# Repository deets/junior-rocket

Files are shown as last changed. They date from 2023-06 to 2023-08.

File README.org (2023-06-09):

* Junior Rocket Firmware

This repository contains the Arduino based firmware for the FAR Junior
two stage rocket.

** RP2040

The state machine is written in C++17. To allow for this to work with
Arduino, the =platform.txt= needs to change so that it enables C++17.

On my system, this is the file

 =~/Library/Arduino15/packages/arduino/hardware/mbed_rp2040/4.0.2/=

The following line must be present:

#+begin_src python
compiler.cpp.extra_flags=-std=gnu++17
#+end_src

Compile with

#+begin_src bash
arduino-cli compile --fqbn arduino:mbed_rp2040:pico
#+end_src

** Arduino Maple

Compile with

#+begin_src bash
arduino-cli compile --fqbn STMicroelectronics:stm32:GenF1 --board-options "pnum=MAPLEMINI_F103CB,opt=oslto"
#+end_src

*** Linker optimization in platform.txt

Lives in

#+begin_src bash
~/Library/Arduino15/packages/STMicroelectronics/hardware/stm32/2.5.0/
#+end_src

for me. Make the following settings look like this:

#+begin_src python
compiler.ldflags=-Wl,--no-warn-rwx-segments,--gc-sections
compiler.c.extra_flags=-ffunction-sections -fdata-sections
compiler.cpp.extra_flags=-ffunction-sections -fdata-sections
#+end_src

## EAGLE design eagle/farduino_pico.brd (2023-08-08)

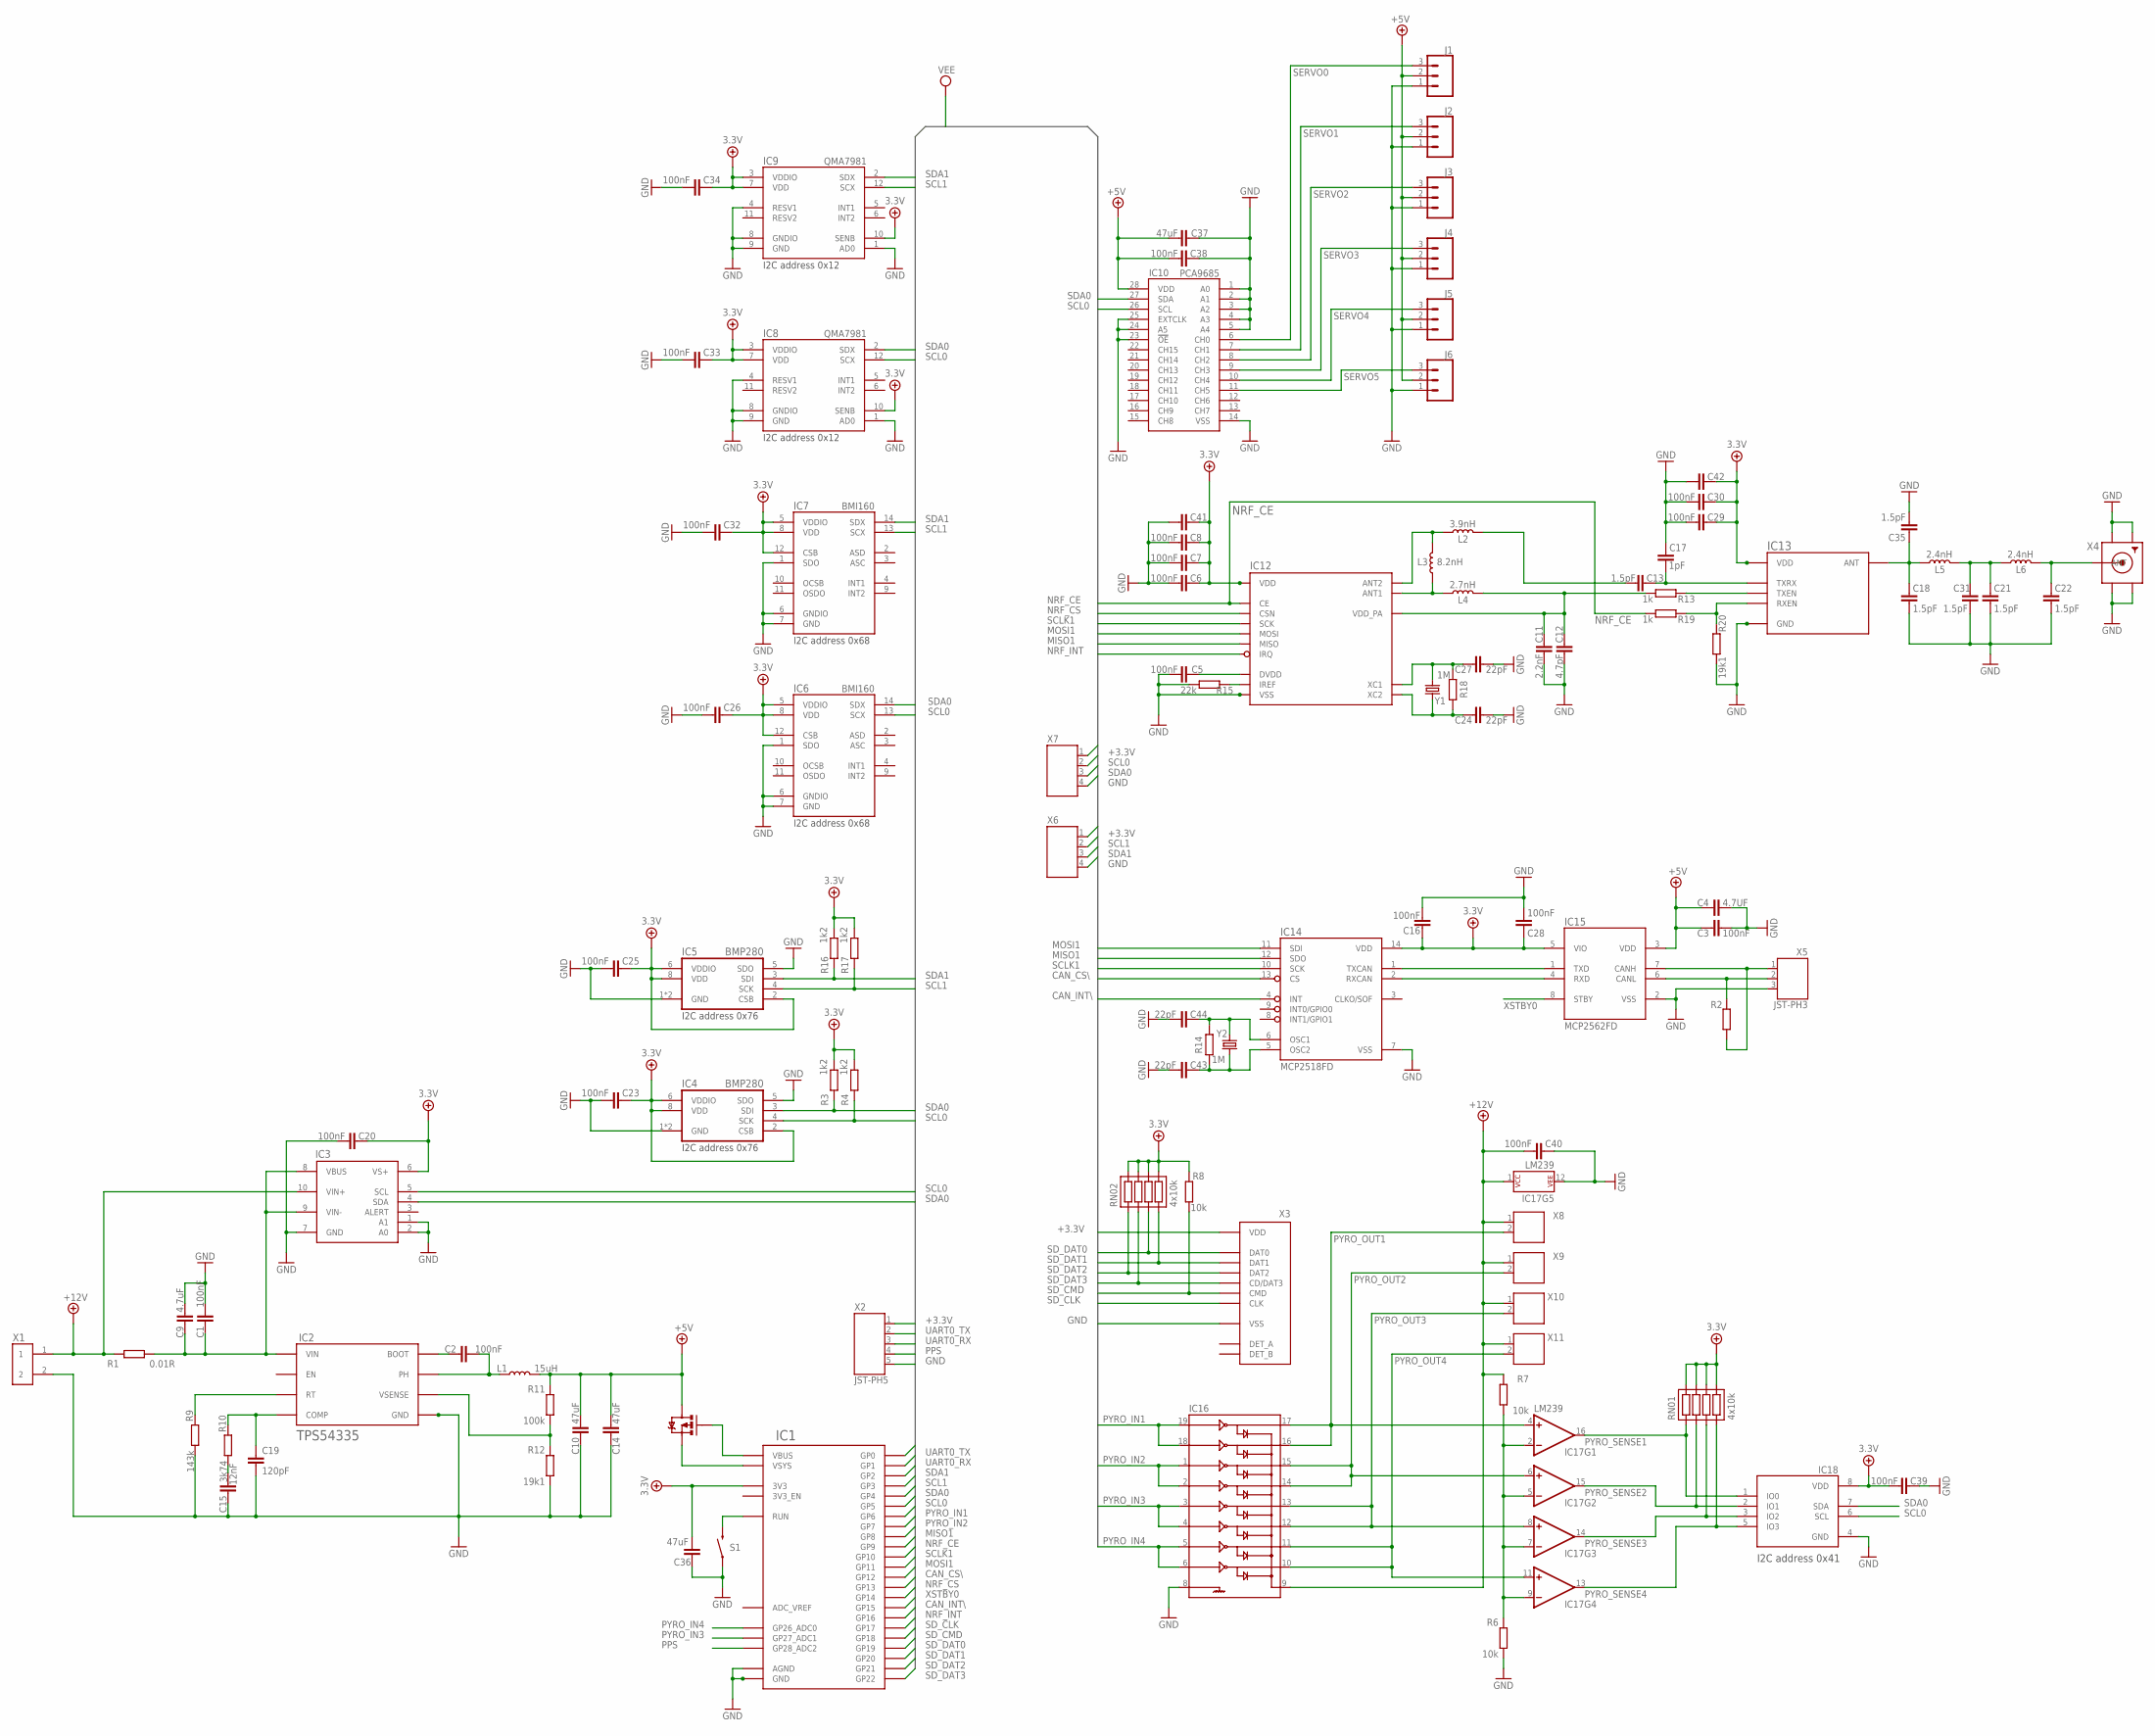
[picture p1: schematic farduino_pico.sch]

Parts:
C1, C2, C3, C5, C6, C7, C8, C16, C20, C23, C25, C26, C28, C29, C30, C32, C33, C34, C38, C39, C40: 100nF; 0402
C4, C41, C42: 4.7UF; 0402
C9: 4.7uF; 1206
C10, C14, C36, C37: 47uF; 1206
C11: 2.2nF; C0402
C12: 4.7pF; C0402
C13, C18, C21, C22, C31, C35: 1.5pF; C0402
C15: 12nF; C0402
C17: 1pF; C0402
C19: 120pF; C0402
C24, C27, C43, C44: 22pF; C0402
IC1: RPI_PICO-SMD; RPI_PICO
IC2: TPS54335ADRCR; VSON-10
IC3: INA226; VSSOP-10
IC4, IC5: BMP280
IC6, IC7: BMI160
IC8, IC9: QMA7981; LGA-12-2X2
IC10: PCA9685; TSSOP-28_4MM
IC12: NRF24L01SMD; QFN20-4X4MM
IC13: RFX2401C; QFN-16-3X3MM
IC14: MCP2518FD; SO14
IC15: MCP2562FD; SO08
IC16: ULN2803QFN; QFN-20-4X4
IC17: LM239; QFN16
IC18: PCA9536; HVSON8
J1, J2, J3, J4, J5, J6: CONN_03; 1X03
L1: 15uH; YSPIA0850
L2: 3.9nH; 0402
L3: 8.2nH; 0402
L4: 2.7nH; 0402
L5, L6: 2.4nH; 0402
Q1: DMG2305UX; SOT23-3@1
R1: 0.01R; R1206
R2: 120; R0402
R3, R4, R16, R17: 1k2; R0402
R6, R7, R8: 10k; R0402
R9: 143k; R0402
R10: 3k74; R0402
R11: 100k; R0402
R12, R20: 19k1; R0402
R13, R19: 1k; R0402
R14, R18: 1M; R0402
R15: 22k; R0402
RN01, RN02: 4x10k; 4D02
S1: MOMENTARY-SWITCH-SPST; TACTILE_SWITCH_SMD_4.2X3.2MM
X1: XT_CONN; XT30_PCB
X2: JST-PH5
X3: 5033981892
X4: SMACONNECTOR; SMA90_DIP
X5: JST-PH3
X6, X7: JST-PH4
X8, X9, X10, X11: JST-PH2
Y1, Y2: CRYSTAL-16MHZ; SMD3225

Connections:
+3.3V: C6.1, C7.1, C8.1, C16.1, C20.2, C23.1, C25.1, C26.1, C28.1, C29.1, C30.1, C32.1, C33.1, C34.1, C36.2, C39.2, C41.2, C42.2, IC1.3V3, IC3.6 (VS+), IC4.2 (CSB), IC4.6 (VDDIO), IC4.8 (VDD), IC5.2 (CSB), IC5.6 (VDDIO), IC5.8 (VDD), IC6.5 (VDDIO), IC6.8 (VDD), IC6.12 (CSB), IC7.5 (VDDIO), IC7.8 (VDD), IC7.12 (CSB), IC8.3 (VDDIO), IC8.7 (VDD), IC8.10 (SENB), IC9.3 (VDDIO), IC9.7 (VDD), IC9.10 (SENB), IC12.7 (VDD), IC12.15 (VDD), IC12.18 (VDD), IC13.14 (VDD), IC13.16 (VDD), IC14.14 (VDD), IC15.5 (VIO), IC18.8 (VDD), R3.2, R4.2, R8.2, R16.2, R17.2, RN01.5, RN01.6, RN01.7, RN01.8, RN02.5, RN02.6, RN02.7, RN02.8, X2.1, X3.4 (VDD), X6.1, X7.1
+5V: C3.1, C4.1, C10.2, C14.2, C37.2, C38.2, IC10.28 (VDD), IC15.3 (VDD), J1.2, J2.2, J3.2, J4.2, J5.2, J6.2, L1.2, Q1.3 (D), R11.2
+12V: C40.2, IC3.10 (VIN+), IC16.9 (COM), IC17.1 (P$V+), R1.2, R7.2, X1.1, X8.1, X9.1, X10.1, X11.1
ANT1: IC12.12 (ANT1), L3.1, L4.1
ANT2: IC12.13 (ANT2), L2.1, L3.2
CAN1_H: IC15.7 (CANH), R2.1, X5.1
CAN1_L: IC15.6 (CANL), R2.2, X5.2
CAN_CS\: IC1.GP12, IC14.13 (CS)
CAN_INT\: IC1.GP15, IC14.4 (INT)
DCDC_BOOT: C2.2, IC2.9 (BOOT)
DCDC_COMP: C19.1, IC2.7 (COMP), R10.1
DCDC_PH: C2.1, IC2.2 (PH), L1.1
DCDC_RT: IC2.10 (RT), R9.1
DVDD: C5.1, IC12.19 (DVDD)
FILTER1: C21.1, C31.1, L5.2, L6.1
GND: C1.1, C3.2, C4.2, C5.2, C6.2, C7.2, C8.2, C9.2, C10.1, C11.2, C12.2, C14.1, C15.2, C16.2, C17.1, C18.2, C19.2, C20.1, C21.2, C22.2, C23.2, C24.2, C25.2, C26.2, C27.2, C28.2, C29.2, C30.2, C31.2, C32.2, C33.2, C34.2, C35.2, C36.1, C37.1, C38.1, C39.1, C40.1, C41.1, C42.1, C43.2, C44.2, IC1.AGND, IC1.GND@1 (GND), IC1.GND@2 (GND), IC1.GND@3 (GND), IC1.GND@4 (GND), IC1.GND@5 (GND), IC1.GND@6 (GND), IC1.GND@7 (GND), IC1.GND@8 (GND), IC2.3 (GND), IC2.4 (GND), IC2.5 (GND), IC2.11 (GND), IC3.1 (A1), IC3.2 (A0), IC3.7 (GND), IC4.1 (GND), IC4.5 (SDO), IC4.7 (GND), IC5.1 (GND), IC5.5 (SDO), IC5.7 (GND), IC6.1 (SDO), IC6.6 (GNDIO), IC6.7 (GND), IC7.1 (SDO), IC7.6 (GNDIO), IC7.7 (GND), IC8.1 (AD0), IC8.4 (RESV1), IC8.8 (GNDIO), IC8.9 (GND), IC9.1 (AD0), IC9.4 (RESV1), IC9.8 (GNDIO), IC9.9 (GND), IC10.1 (A0), IC10.2 (A1), IC10.3 (A2), IC10.4 (A3), IC10.5 (A4), IC10.14 (VSS), IC10.23 (!OE), IC10.24 (A5), IC10.25 (EXTCLK), IC12.0 (VSS), IC12.8 (VSS), IC12.14 (VSS), IC12.17 (VSS), IC12.20 (VSS), IC13.1 (GND), IC13.2 (GND), IC13.3 (GND), IC13.7 (GND), IC13.8 (GND), IC13.9 (GND), IC13.11 (GND), IC13.12 (GND), IC13.15 (GND), IC13.17 (GND), IC14.7 (VSS), IC15.2 (VSS), IC16.8 (GND), IC17.12 (P$V-), IC18.4 (GND), J1.1, J2.1, J3.1, J4.1, J5.1, J6.1, R6.1, R9.2, R12.1, R15.1, R20.1, S1.1, S1.2 (1), X1.2, X2.5, X3.6 (VSS), X4.GND1, X4.GND2, X4.GND3, X4.GND4, X5.3, X6.4, X7.4
IREF: IC12.16 (IREF), R15.2
MISO1: IC1.GP8, IC12.5 (MISO), IC14.12 (SDO)
MOSI1: IC1.GP11, IC12.4 (MOSI), IC14.11 (SDI)
unnamed: C15.1, R10.2
NRF_CE: IC1.GP9, IC12.1 (CE), R19.1
NRF_CS: IC1.GP13, IC12.2 (CSN)
NRF_INT: IC1.GP16, IC12.6 (IRQ)
NRF_SIGNAL: C13.2, L2.2
OSC1_40MHZ: C44.1, IC14.6 (OSC1), R14.2, Y2.3 (2)
OSC2_40MHZ: C43.1, IC14.5 (OSC2), R14.1, Y2.1
PA_ANT: C18.1, C35.1, IC13.10 (ANT), L5.1
PPS: IC1.GP28_A2 (GP28_ADC2), X2.4
PYRO_IN1: IC1.GP6, IC16.18 (IN2), IC16.19 (IN1)
PYRO_IN2: IC1.GP7, IC16.1 (IN3), IC16.2 (IN4)
PYRO_IN3: IC1.GP27_A1 (GP27_ADC1), IC16.3 (IN5), IC16.4 (IN6)
PYRO_IN4: IC1.GP26_A0 (GP26_ADC0), IC16.5 (IN7), IC16.6 (IN8)
PYRO_OUT1: IC16.16 (OUT2), IC16.17 (OUT1), IC17.4 (+IN), X8.2
PYRO_OUT2: IC16.14 (OUT4), IC16.15 (OUT3), IC17.6 (+IN), X9.2
PYRO_OUT3: IC16.12 (OUT6), IC16.13 (OUT5), IC17.8 (+IN), X10.2
PYRO_OUT4: IC16.10 (OUT8), IC16.11 (OUT7), IC17.11 (+IN), X11.2
PYRO_SENSE1: IC17.16 (OUT), IC18.1 (IO0), RN01.1
PYRO_SENSE2: IC17.15 (OUT), IC18.2 (IO1), RN01.2
PYRO_SENSE3: IC17.14 (OUT), IC18.3 (IO2), RN01.3
PYRO_SENSE4: IC17.13 (OUT), IC18.5 (IO3), RN01.4
RUN: IC1.RUN, S1.3 (2), S1.4 (2)
RXCAN1: IC14.2 (RXCAN), IC15.4 (RXD)
RXEN: IC13.6 (RXEN), R19.2, R20.2
SCL0: IC1.GP5, IC3.5 (SCL), IC4.4 (SCK), IC6.13 (SCX), IC8.12 (SCX), IC10.26 (SCL), IC18.6 (SCL), R4.1, X7.2
SCL1: IC1.GP3, IC5.4 (SCK), IC7.13 (SCX), IC9.12 (SCX), R17.1, X6.2
SCLK1: IC1.GP10, IC12.3 (SCK), IC14.10 (SCK)
SDA0: IC1.GP4, IC3.4 (SDA), IC4.3 (SDI), IC6.14 (SDX), IC8.2 (SDX), IC10.27 (SDA), IC18.7 (SDA), R3.1, X7.3
SDA1: IC1.GP2, IC5.3 (SDI), IC7.14 (SDX), IC9.2 (SDX), R16.1, X6.3
SD_CLK: IC1.GP17, X3.5 (CLK)
SD_CMD: IC1.GP18, R8.1, X3.3 (CMD)
SD_DAT0: IC1.GP19, RN02.3, X3.7 (DAT0)
SD_DAT1: IC1.GP20, RN02.4, X3.8 (DAT1)
SD_DAT2: IC1.GP21, RN02.1, X3.1 (DAT2)
SD_DAT3: IC1.GP22, RN02.2, X3.2 (CD/DAT3)
SERVO0: IC10.6 (CH0), J1.3
SERVO1: IC10.7 (CH1), J2.3
SERVO2: IC10.8 (CH2), J3.3
SERVO3: IC10.9 (CH3), J4.3
SERVO4: IC10.10 (CH4), J5.3
SERVO5: IC10.11 (CH5), J6.3
SMA_RF: C22.1, L6.2, X4.ANTENNA (ANT)
TXCAN1: IC14.1 (TXCAN), IC15.1 (TXD)
TXEN: IC13.5 (TXEN), R13.2
TXRX: C13.1, C17.2, IC13.4 (TXRX)
UART0_RX: IC1.GP1, X2.3
UART0_TX: IC1.GP0, X2.2
UREF: IC17.2 (-IN), IC17.5 (-IN), IC17.7 (-IN), IC17.9 (-IN), R6.2, R7.1
VBUS: IC1.VBUS, Q1.1 (G)
VDD_PA: C11.1, C12.1, IC12.11 (VDD_PA), L4.2, R13.1
VIN: C1.2, C9.1, IC2.1 (VIN), IC3.8 (VBUS), IC3.9 (VIN-), R1.1
VSENSE: IC2.6 (VSENSE), R11.1, R12.2
VSYS: IC1.VSYS, Q1.2 (S)
XC1_16MHZ: C27.1, IC12.10 (XC1), R18.1, Y1.1
XC2_16MHZ: C24.1, IC12.9 (XC2), R18.2, Y1.3 (2)
XSTBY0: IC1.GP14, IC15.8 (STBY)

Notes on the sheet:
I2C address 0x41
I2C address 0x76
I2C address 0x68
I2C address 0x12

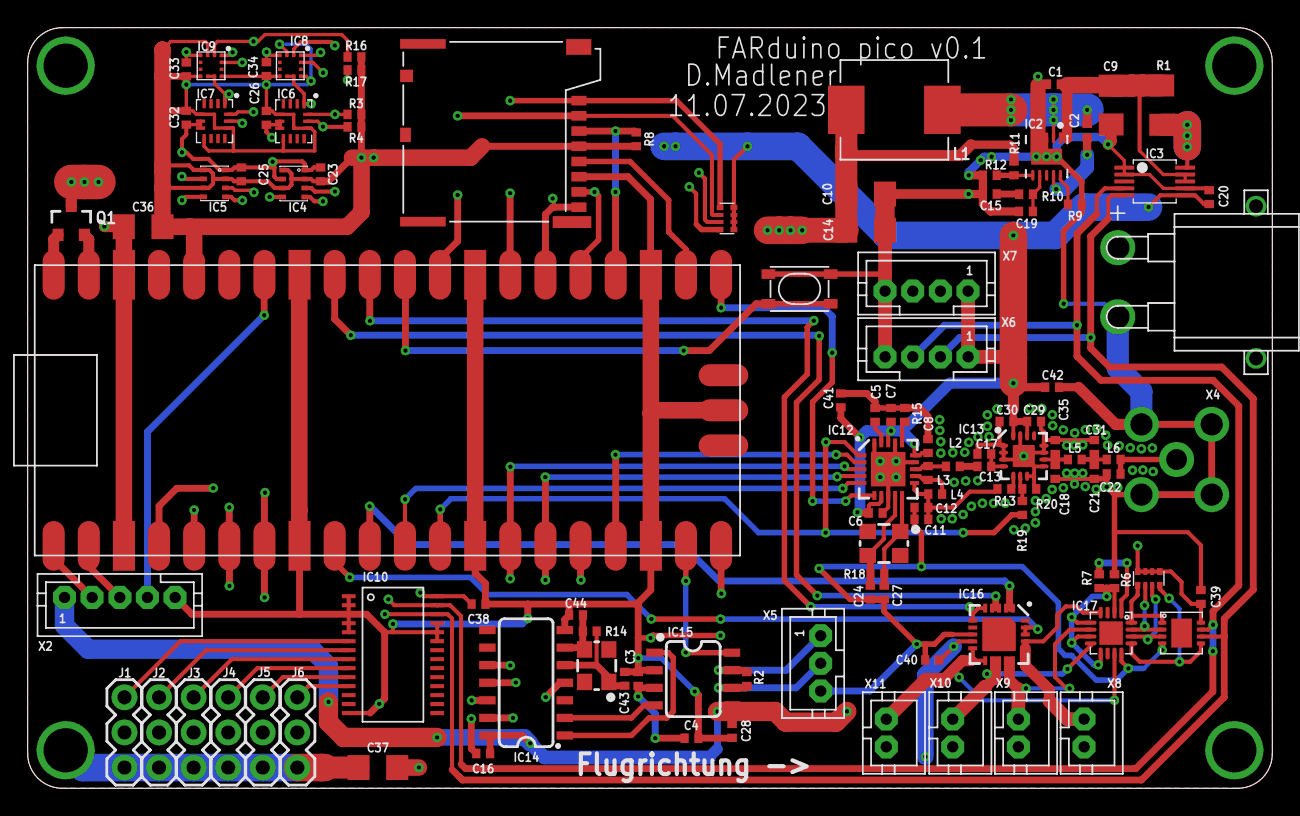
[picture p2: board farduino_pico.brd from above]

Board: 4 copper layers, 90.0 x 55.0 mm, 109 parts (0 on the bottom side), 75 nets.

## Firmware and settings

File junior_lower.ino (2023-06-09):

#include "farduino_constants.h"
// Must come after farduino_constants.h !
#include "rtttl_songs.h"
#include "farduino_types.h"
#include "farduino_utilities.h"
#include "ring_buffer.h"

#include "junior-rocket-state.hpp"
#include "state-reactions.hpp"

#include <I2Cdev.h>
#include <Wire.h>
#include <MPU9250.h>
#include <Adafruit_Sensor.h>
#include <Adafruit_BMP280.h>
#include <Adafruit_BNO055.h>
#include <utility/imumaths.h>

#ifdef USE_SD_CARD
#define USE_STANDARD_SPI_LIBRARY 2  // See SdFatConfig.h
#include <SPI.h>
#include <SdFat.h>
#endif

#include <RF24.h>

#include <chrono>

//#define farduino_maple_v1 1
#define farduino_maple_v2 1
//#define farduino_maple_v3 1



#define isdigit(n) (n >= '0' && n <= '9')

// class default I2C address is 0x68
// specific I2C addresses may be passed as a parameter here
// AD0 low  = 0x68 (default for InvenSense evaluation board)
// AD0 high = 0x69

char my_name[16];
char my_line[64];
char response[64];

unsigned int sample_count = 0;
unsigned int file_count = 0;

double temperature;
double pressure;
double altitude;

double raw_acc[3];
double raw_omega[3];
double raw_B[3];

double acc[3];
double omega[3];
double omega_0[3] = { 0.0, 0.0, 0.0 };
double B[3];

double norm_acc;
double norm_omega;

unsigned char GPS_checksum = 0;
byte unsigned GPS_pointer = 0;
bool receiving_GPS;
char GPS_sentence[128];

//the pressure sensor is necessary
Adafruit_BMP280 met;

MPU9250 imu_mpu9250;
bool mpu9250_present = false;

Adafruit_BNO055 imu_bno055 = Adafruit_BNO055(-1, 0x28);
bool bno055_present = false;

byte flight_address[6] = "LOWER";
byte ground_address[6] = "GRND1";

char request[32] = "abcdefghijklmnopqrstuvwxyz01234";

CircularBuffer ring(256);
RF24 radio_nrf24(NRF24_CE_PIN, NRF24_CS_PIN);

bool nrf24l01_present = false;


#ifdef USE_SD_CARD
//SD constants and variables
const uint8_t chipSelect = PB12;
SPIClass spi2;
SdFat sd(&spi2);

bool SD_present = false;
SdFile dataFile;
bool file_exists;
#endif

StateReactions state_reactions(radio_nrf24);
far::junior::JuniorRocketState state_machine(state_reactions);

void setup() {

  double altitude;
  unsigned long met_timestamp;
  double sigma_w;

  unsigned long mean_count;

  inertial_measurement_t imu_data;

  //set all pyro pins as outputs and inactive
  pinMode(PYRO0, OUTPUT);
  digitalWrite(PYRO0, LOW);
  pinMode(PYRO1, OUTPUT);
  digitalWrite(PYRO1, LOW);
  pinMode(PYRO2, OUTPUT);
  digitalWrite(PYRO2, LOW);
  pinMode(PYRO3, OUTPUT);
  digitalWrite(PYRO3, LOW);

  //join I2C bus
  Wire.begin();
  Wire.setClock(100000);

  //open USB com port
  #ifndef RASPBERRYPI_PICO
  Serial.begin(115200);
  #else
  Serial.begin(115200);
  #endif

  //serial port #1 set to 9600 8n1 for GPS data stream
  Serial1.begin(9600);

  delay(2000);
  Serial.println(F("FARduino Maple v0.2"));


  nrf24l01_present = radio_nrf24.begin();
  if (nrf24l01_present) {
    Serial.print(F("Initializing nrf24L01+..."));

    radio_nrf24.setPayloadSize(32);
    radio_nrf24.setAutoAck(true);
    radio_nrf24.setPALevel(RF24_PA_LOW);
    radio_nrf24.openWritingPipe(ground_address);
    radio_nrf24.openReadingPipe(1, flight_address);
    radio_nrf24.startListening();

    Serial.println(F("done."));
  } else {
    Serial.println(F("<!> nrf24L01+ not detected"));
  }

  //initialize I2C devices

  mpu9250_present = imu_mpu9250.testConnection();
  if (mpu9250_present) {
    Serial.print(F("Initializing MPU9250..."));
    imu_mpu9250.initialize();
    //set gyroscope scale to +/-2000°/s
    imu_mpu9250.setFullScaleGyroRange(MPU9250_GYRO_FS_2000);
    //set acceleration scale to +/-16g
    imu_mpu9250.setFullScaleAccelRange(MPU9250_ACCEL_FS_16);
    Serial.println(F("done."));
  } else {
    Serial.println("<!> MPU9250 not detected");
  }

  bno055_present = imu_bno055.begin();
  if (bno055_present) {
    Serial.print(F("Initializing BNO055..."));
    imu_bno055.setExtCrystalUse(true);
    Serial.println("ready.");
  } else {
    Serial.println("<!> BNO055 not detected");
  }

  // Initialize the SD card at SPI_HALF_SPEED to avoid bus errors with
  // breadboards.  use SPI_FULL_SPEED for better performance.
  #ifdef USE_SD_CARD
  SD_present = sd.begin(chipSelect, SPI_FULL_SPEED);
  if (!SD_present) {
    Serial.println("<!> no SD card found");
  } else {
    Serial.println("SD card initialized");
    //search for next free file dataXXXX.txt
    do {
      sprintf(my_name, "data%04d.txt", file_count++);
      Serial.print("checking ");
      Serial.println(my_name);

      file_exists = !dataFile.open(my_name, O_CREAT | O_WRITE | O_EXCL);
      if (!file_exists) {
        Serial.print("file ");
        Serial.print(my_name);
        Serial.println(" created");
      }
    } while (file_exists);
  }
  #endif
  

  if (!met.begin(0x76)) {
    Serial.println(F("<!> BMP280 not detected"));
    //halt program if no pressure sensor is detected
    exit(-1);
  }
  
  //indicate readiness for operator
  play_rtttl(never_song);

}



//central LOOP

void loop() {

  char sentence[100];

  unsigned long met_timestamp;
  unsigned long flight_time;
  unsigned long mean_count;
  unsigned long delta_time;
  double delta_pressure;

  const auto imu_timestamp = std::chrono::steady_clock::now();
#ifdef farduino_maple_v1
  if (mpu9250_present) {
    get_mpu9250_data(raw_acc[0], raw_acc[1], raw_acc[2], raw_omega[0], raw_omega[1], raw_omega[2], raw_B[0], raw_B[1], raw_B[2]);
    
    acc[0] = raw_acc[0]/ONE_G;
    acc[1] = raw_acc[1]/ONE_G;
    acc[2] = raw_acc[2]/ONE_G;
  
    //calculate norm of acceleration vector in g
    norm_acc = sqrt(acc[0] * acc[0] + acc[1] * acc[1] + acc[2] * acc[2]);
  
    omega[0] = raw_omega[0]/ONE_DEG_PER_SECOND;
    omega[1] = raw_omega[1]/ONE_DEG_PER_SECOND;
    omega[2] = raw_omega[2]/ONE_DEG_PER_SECOND;
  
    norm_omega = sqrt(raw_omega[0] * raw_omega[0] + raw_omega[1] * raw_omega[1] + raw_omega[2] * raw_omega[2]);
  
    construct_IMU_sentence(imu_timestamp, acc, omega, raw_B, &sentence[0]);
    send_sentence_to_all(&sentence[0]);
  }
#elsif
  if (bno055_present) {
    get_bno055_data(raw_acc[0], raw_acc[1], raw_acc[2], raw_omega[0], raw_omega[1], raw_omega[2], raw_B[0], raw_B[1], raw_B[2]);
    
    acc[0] = raw_acc[0]/ONE_G;
    acc[1] = raw_acc[1]/ONE_G;
    acc[2] = raw_acc[2]/ONE_G;
  
    //calculate norm of acceleration vector in g
    norm_acc = sqrt(acc[0] * acc[0] + acc[1] * acc[1] + acc[2] * acc[2]);
  
    omega[0] = raw_omega[0]/ONE_DEG_PER_SECOND;
    omega[1] = raw_omega[1]/ONE_DEG_PER_SECOND;
    omega[2] = raw_omega[2]/ONE_DEG_PER_SECOND;
  
    norm_omega = sqrt(raw_omega[0] * raw_omega[0] + raw_omega[1] * raw_omega[1] + raw_omega[2] * raw_omega[2]);
    
    construct_IMU_sentence(imu_timestamp, acc, omega, raw_B, &sentence[0]);
    send_sentence_to_all(&sentence[0]);
  }
#endif

  
  get_MET_data(met_timestamp, temperature, pressure, altitude);

  construct_MET_sentence(met_timestamp, pressure, temperature, altitude, &sentence[0]);
  send_sentence_to_all(&sentence[0]);
  
  bool gps_available = get_GPS_data();
  if (gps_available) {
    send_sentence_to_all(&GPS_sentence[0]);
  }


  #ifdef USE_SD_CARD
  sample_count++;

  if (SD_present) {
    // Force data to SD and update the directory entry to avoid data loss.
    if (!dataFile.sync() || dataFile.getWriteError()) {
      //sd.errorHalt(F("write error"));
    }

    if (sample_count >= MAX_SAMPLE_COUNT && state_reactions.safe_to_flush_sd_card()) {
      dataFile.close();

      do {
        sprintf(my_name, "data%04d.txt", file_count++);
        Serial.print("creating file ");
        Serial.println(my_name);
        file_exists = !dataFile.open(my_name, O_CREAT | O_WRITE | O_EXCL);
        if (file_exists) {
          Serial.println("file exists.");
        } else {
          Serial.println("new file created");
        }
      } while (file_exists);

      sample_count = 0;
    }
  }
  #endif
  state_machine.drive(imu_timestamp, pressure, norm_acc);
}


void send_sentence(const char* message) {

  ring.write(message, strlen(message));

  radio_nrf24.stopListening();
  while (ring.filling() >= 32) {
    ring.read(&response[0], 32);
    radio_nrf24.writeFast(&response[0], 32);
  }

  radio_nrf24.txStandBy();
  radio_nrf24.startListening();
}


bool get_GPS_data(void) {

  char cipher = 0;
  char first_char;
  char second_char;
  unsigned char received_checksum;

  while (Serial1.available()) {
    cipher = Serial1.read();

    if (cipher == '$') {
      GPS_checksum = 0;
      GPS_pointer = 0;
      receiving_GPS = true;
    }

    GPS_sentence[GPS_pointer] = cipher;
    if (GPS_pointer < 128) {
      GPS_pointer++;
    }

    if (cipher == '*') {
      receiving_GPS = false;
    } else if ((cipher != '$') && receiving_GPS) {
      GPS_checksum ^= cipher;
    } else if (cipher == 0x0A) {
      first_char = GPS_sentence[GPS_pointer - 4];
      second_char = GPS_sentence[GPS_pointer - 3];

      if (first_char > '9') {
        first_char = first_char - 'A' + 10;
      } else {
        first_char = first_char - '0';
      }

      if (second_char > '9') {
        second_char = second_char - 'A' + 10;
      } else {
        second_char = second_char - '0';
      }

      received_checksum = (first_char << 4) + second_char;

      //Serial1.println(received_checksum,HEX);
      //Serial1.println(GPS_checksum,HEX);

      if (GPS_checksum == received_checksum) {
        GPS_sentence[GPS_pointer] = 0;
        return true;
      } else {
        return false;
      }
    }
  }
  return false;
}




void get_mpu9250_data(double& acc_x, double& acc_y, double& acc_z, double& omega_x, double& omega_y, double& omega_z, double& mag_x, double& mag_y, double& mag_z) {

  int16_t ax, ay, az;
  int16_t wx, wy, wz;
  int16_t Bx, By, Bz;

  imu_mpu9250.getMotion9(&ax, &ay, &az, &wx, &wy, &wz, &Bx, &By, &Bz);

  acc_x = (double)ax;
  acc_y = (double)ay;
  acc_z = (double)az;

  omega_x = (double)wx - omega_0[0];
  omega_y = (double)wy - omega_0[1];
  omega_z = (double)wz - omega_0[2];

  mag_x = (double)Bx;
  mag_y = (double)By;
  mag_z = (double)Bz;
}


void get_bno055_data(double& acc_x, double& acc_y, double& acc_z, double& omega_x, double& omega_y, double& omega_z, double& mag_x, double& mag_y, double& mag_z) {

  sensors_event_t magneticData, angVelocityData, accelData;

  imu_bno055.getEvent(&magneticData, Adafruit_BNO055::VECTOR_MAGNETOMETER);
  imu_bno055.getEvent(&angVelocityData, Adafruit_BNO055::VECTOR_GYROSCOPE);
  imu_bno055.getEvent(&accelData, Adafruit_BNO055::VECTOR_ACCELEROMETER);

  acc_x = accelData.acceleration.x;
  acc_y = accelData.acceleration.y;
  acc_z = accelData.acceleration.z;

  omega_x = angVelocityData.gyro.x;
  omega_y = angVelocityData.gyro.y;
  omega_z = angVelocityData.gyro.z;

  mag_x = magneticData.magnetic.x;
  mag_y = magneticData.magnetic.y;
  mag_z = magneticData.magnetic.z;
}





void get_MET_data(unsigned long& timestamp, double& temperature, double& pressure, double& altitude) {

  timestamp = get_timestamp();
  temperature = met.readTemperature();
  pressure = met.readPressure() / 100.0;
  if(const auto ground_pressure = state_machine.ground_pressure())
  {
    altitude = met.readAltitude(*ground_pressure);
  }
  else
  {
    altitude = -1.0;
  }
}


void mean_pressure(int n, double& mean_p, double& sigma_p) {

  double sum = 0.0;
  double sum2 = 0.0;

  unsigned long timestamp;
  double temp;
  double p;
  double h;

  for (int k = 0; k < n; k++) {
    get_MET_data(timestamp, temp, p, h);

    sum += p;
    sum2 += p * p;
  }

  mean_p = sum / n;
  sigma_p = sqrt((sum2 - n * mean_p * mean_p) / (n - 1));
}


void mean_inertial(int n, inertial_measurement_t& data) {

  double sum_acc[3] = { 0.0, 0.0, 0.0 };
  double sum_acc2[3] = { 0.0, 0.0, 0.0 };

  double sum_w[3] = { 0.0, 0.0, 0.0 };
  double sum_w2[3] = { 0.0, 0.0, 0.0 };

  double sum_B[3] = { 0.0, 0.0, 0.0 };
  double sum_B2[3] = { 0.0, 0.0, 0.0 };



  unsigned long timestamp;
  double norm_acc[3];
  double norm_omega[3];
  double B[3];

  for (int k = 0; k < n; k++) {
    get_mpu9250_data(norm_acc[0], norm_acc[1], norm_acc[2], norm_omega[0], norm_omega[1], norm_omega[2], B[0], B[1], B[2]);

    for (int j = 0; j < 3; j++) {
      sum_acc[j] += norm_acc[j];
      sum_acc2[j] += norm_acc[j] * norm_acc[j];

      sum_w[j] += norm_omega[j];
      sum_w2[j] += norm_omega[j] * norm_omega[j];

      sum_B[j] += B[j];
      sum_B2[j] += B[j] * B[j];
    }
  }


  for (int j = 0; j < 3; j++) {
    data.mean_a[j] = sum_acc[j] / n;
    data.sigma_a[j] = sqrt((sum_acc2[j] - n * data.mean_a[j] * data.mean_a[j]) / (n - 1));

    data.mean_w[j] = sum_w[j] / n;
    data.sigma_w[j] = sqrt((sum_w2[j] - n * data.mean_w[j] * data.mean_w[j]) / (n - 1));

    data.mean_B[j] = sum_B[j] / n;
    data.sigma_B[j] = sqrt((sum_B2[j] - n * data.mean_B[j] * data.mean_B[j]) / (n - 1));
  }
}

void send_sentence_to_all(const char* sentence)
{
    Serial.print(sentence);
    #ifdef USE_SD_CARD
    if (SD_present) {
      dataFile.print(sentence);
    }
    #endif
    if (nrf24l01_present) {
      send_sentence(sentence);
    }
}

#include <sys/time.h>
#ifndef RASPBERRYPI_PICO
extern "C" int gettimeofday( struct timeval *tv, void *tzvp )
{
  static bool initialized = false;
  static uint64_t usec;
  static uint64_t sec;
  static uint64_t last_timestamp;  
  if(!initialized)
  {
    initialized = true;
    sec = usec = 0;
    last_timestamp = micros();
  }
  else
  {
    uint64_t now = micros();
    uint64_t diff = timestamp_difference(now, last_timestamp);
    usec += diff;
    sec += usec / 1000000;
    usec %= 1000000;
  }
    
  tv->tv_sec = sec;
  tv->tv_usec = usec;
  return 0;
}
#endif

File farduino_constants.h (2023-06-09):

#ifndef __FARDUINO_CONSTANTS_H__
#define __FARDUINO_CONSTANTS_H__

//all times in microseconds
#define MIN_ACCELERATION_TIME 400000

#ifdef farduino_maple_v1
#define ONE_G 2048.0
#define ONE_DEG_PER_SECOND 16.4
#else
#define ONE_G 1000.0
#define ONE_DEG_PER_SECOND 16.0
#endif

#define ONE_SECOND 1000000
#define MIN_FLIGHT_TIME 5000000
#define MAX_TIME_TO_PEAK 7000000
#define MOTOR_BURNOUT_TIME 2100000
#define PEAK_DISCRIMINATION_TIME 800000
#define MAX_SAMPLE_COUNT 200000
#define STAGE_DELAY 1000000
#define MIN_PRESSURE_DROP -0.8

#ifdef farduino_maple_v1
//#define USE_SD_CARD
#define PYRO0 PA14
#define PYRO1 PA13
#define PYRO2 PA12
#define PYRO3 PA11
#define TONE_PIN PA2
#define NRF24_CE_PIN PA8
#define NRF24_CS_PIN PA4
#elif defined(RASPBERRYPI_PICO)
#define PYRO0 p14
#define PYRO1 p13
#define PYRO2 p12
#define PYRO3 p11
#define TONE_PIN p2
#define NRF24_CE_PIN p8
#define NRF24_CS_PIN p4
#else
//#define USE_SD_CARD
#define PYRO0 PB5
#define PYRO1 PB4
#define PYRO2 PB3
#define PYRO3 PA15
#define TONE_PIN PA2
#define NRF24_CE_PIN PC15
#define NRF24_CS_PIN PA4

#endif

#endif

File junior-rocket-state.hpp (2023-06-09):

// (c) Diez Roggisch, 2023
// SPDX-License-Identifier: MIT
#pragma once

#include <chrono>
#include <ostream>

namespace far::junior {

using timestamp_t = std::chrono::steady_clock::time_point;
using duration_t = std::chrono::steady_clock::duration;

}


namespace tfa {

std::ostream& operator<<(std::ostream&, const far::junior::duration_t&);

}

#include "timed-finite-automaton.hpp"
#include "statistics.hpp"
#include <cstdint>
#include <optional>

namespace far::junior {

using timestamp_t = std::chrono::steady_clock::time_point;
using duration_t = std::chrono::steady_clock::duration;
using namespace std::chrono_literals;


enum class state
{
  // Start state
  IDLE,
  // Compute the ground pressuer by averaging
  // pressure over a certain amount of time
  ESTABLISH_GROUND_PRESSURE,
  // After stable pressure is detected
  WAIT_FOR_LAUNCH,
  // We measured acceleration beyond the threshold,
  // but this needs to be stable for a while
  // to qualify as ACCELERATING
  ACCELERATION_DETECTED,
  // We reached the acceleration phase,
  ACCELERATING,
  // once pressure fell off enough, we declare us being
  // launched.
  LAUNCHED,
  // The motor cut out
  BURNOUT,
  // after a second, separate
  SEPARATION,
  // shortly after the separation, we are in coasting
  COASTING,
  // We detected a pressure drop, and thus reached
  // the peak.
  PEAK_REACHED,
  FALLING_,
  MEASURE_FALLING_PRESSURE1,
  MEASURE_FALLING_PRESSURE2,
  MEASURE_FALLING_PRESSURE3,
  DROUGE_OPENED,
  DROUGE_FAILED,
  LANDED,
};

struct timeouts {
  static constexpr duration_t ACCELERATION = 400ms;
  static constexpr duration_t SEPARATION_TIMEOUT = 1s;
  static constexpr duration_t MOTOR_BURNTIME = 2500ms;
  static constexpr duration_t FALLING_PRESSURE_TIMEOUT = 1s;
};

enum class pressure_drop {
  LINEAR,
  QUADRATIC,
};

// We seem to reach a shoulder of ~20m/s^2, so
// this looks safe
constexpr float LAUNCH_ACCELERATION_THRESHOLD = 15.0;
// We only get an absolute acceleration, so it is never
// below zero, instead we need to
constexpr float FREEFALL_ACCELERATION_THRESHOLD = 3.0;
// mbar difference between our ground pressure and
// the height we consider safely as "launched".
constexpr float LAUNCH_PRESSURE_DIFFERENTIAL = 5.0;
// The drop in pressure from the minimum we
// accept to say "we've peaked"
constexpr float PEAK_PRESSURE_MARGIN = .6;
// Apogee according to simulation
constexpr duration_t APOGEE_TIME = 6565ms;
// Together with APOGEE_TIME used to trigger
// chute ejection.
constexpr duration_t APOGEE_DETECTION_MARGIN = 5s;
constexpr float INITIAL_PRESSURE_VARIANCE = 1.0;
constexpr float PRESSURE_VARIANCE_THRESHOLD = 3.0;

enum class event {
  GROUND_PRESSURE_ESTABLISHED,
  // Happens when the difference between ground pressure
  // and measured pressure is bigger than LAUNCH_PRESSURE_DIFFERENTIAL
  // which means that we are higher in the air. The name is thus
  // inverted
  PRESSURE_BELOW_LAUNCH_THRESHOLD,
  PRESSURE_ABOVE_LAUNCH_THRESHOLD,
  PRESSURE_PEAK_REACHED,
  ACCELERATION_BELOW_THRESHOLD,
  ACCELERATION_ABOVE_THRESHOLD,
  ACCELERATION_AROUND_ZERO,
  EXPECTED_APOGEE_TIME_REACHED,
  PRESSURE_LINEAR,
  PRESSURE_QUADRATIC,
  RESTART_PRESSURE_MEASUREMENT,
};

#define M_UNUSED(variable) (void)variable;

struct StateObserver {
  virtual void data(timestamp_t timestamp, float pressure, float acceleration)
  {
    M_UNUSED(timestamp);
    M_UNUSED(pressure);
    M_UNUSED(acceleration);
  }

  virtual void state_changed(timestamp_t timestamp, state)
  {
    M_UNUSED(timestamp);
  }
  virtual void event_produced(timestamp_t timestamp, event)
  {
    M_UNUSED(timestamp);
  }

  virtual void elapsed(timestamp_t timestamp, duration_t elapsed)
  {
    M_UNUSED(timestamp);
    M_UNUSED(elapsed);
  }
};


class JuniorRocketState {
  using state_machine_t = tfa::TimedFiniteAutomaton<state, event, timestamp_t>;

public:

  JuniorRocketState(StateObserver&);
  JuniorRocketState(const JuniorRocketState&) = delete;
  JuniorRocketState& operator=(const JuniorRocketState&) = delete;
  JuniorRocketState(JuniorRocketState&&) = delete;

  void dot(std::ostream& os);
  void drive(timestamp_t, float, float);
  std::optional<duration_t> flighttime() const;
  std::optional<float> ground_pressure() const;

private:
  void process_pressure(float pressure);
  void produce_events(timestamp_t timestamp, float pressure, float acceleration);
  void handle_state_transition(state to, float pressure);
  void feed(timestamp_t timestamp, event);
  void assess_pressure_drop();

  state_machine_t _state_machine;

  std::optional<timestamp_t> _last_timestamp;
  std::optional<float> _ground_pressure;
  std::optional<timestamp_t> _liftoff_timestamp;

  StateObserver& _state_observer;

  std::optional<deets::statistics::ArrayStatistics<float, 2>> _ground_pressure_stats;
  std::optional<deets::statistics::ArrayStatistics<float, 10>> _peak_pressure_stats;
  float _pressure_measurements[3];
  std::optional<pressure_drop> _pressure_drop_assessment;
  std::optional<float> _peak_pressure;
};

#ifdef USE_IOSTREAM
// To allow graphviz output
std::ostream& operator<<(std::ostream&, const state&);
std::ostream& operator<<(std::ostream&, const event&);
#endif

} // namespace far::junior

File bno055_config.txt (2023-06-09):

x - > -x
y -> -z
z -> -y

AXIS_MAP_CONFIG : 0b00011000 = 0x18
  AXIS_MAP_SIGN : 0b00000111 = 0x03
  
     ACC_Config : 0b00010011 = 0x13 [Normal mode, 125Hz, 16g]
	   UNIT_SEL : 0b10000001 = 0x81

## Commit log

2023-06-09 Pull in upstream repo code
    This is awkward, but due to the limitations of the Arduino platform
    I don't see a better way - submodules aren't really working here.
2023-06-09 Replace current state logic with state machine and observer
    [junior_lower.ino]
2023-06-09 Pulled in latest code from upstream
    This avoids a preprocessor name conflict and removes iostream usage
    [farduino_constants.h, junior-rocket-state.hpp, junior_lower.ino]
2023-08-08 FARduino pico schematic and board file
    [farduino_pico.brd, farduino_pico.sch]

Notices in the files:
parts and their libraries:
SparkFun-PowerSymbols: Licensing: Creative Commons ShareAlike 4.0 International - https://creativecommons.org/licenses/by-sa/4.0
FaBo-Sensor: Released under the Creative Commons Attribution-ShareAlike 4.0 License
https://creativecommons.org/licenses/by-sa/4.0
